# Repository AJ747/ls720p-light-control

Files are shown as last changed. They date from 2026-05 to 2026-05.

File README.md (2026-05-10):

# LS720P Light Control PCB
Controller for LS720P light using ATTINY5. Brightness is controlled using potentiometer. +5V input and switch for power on/off. Made in KiCad 10.

# Schematic

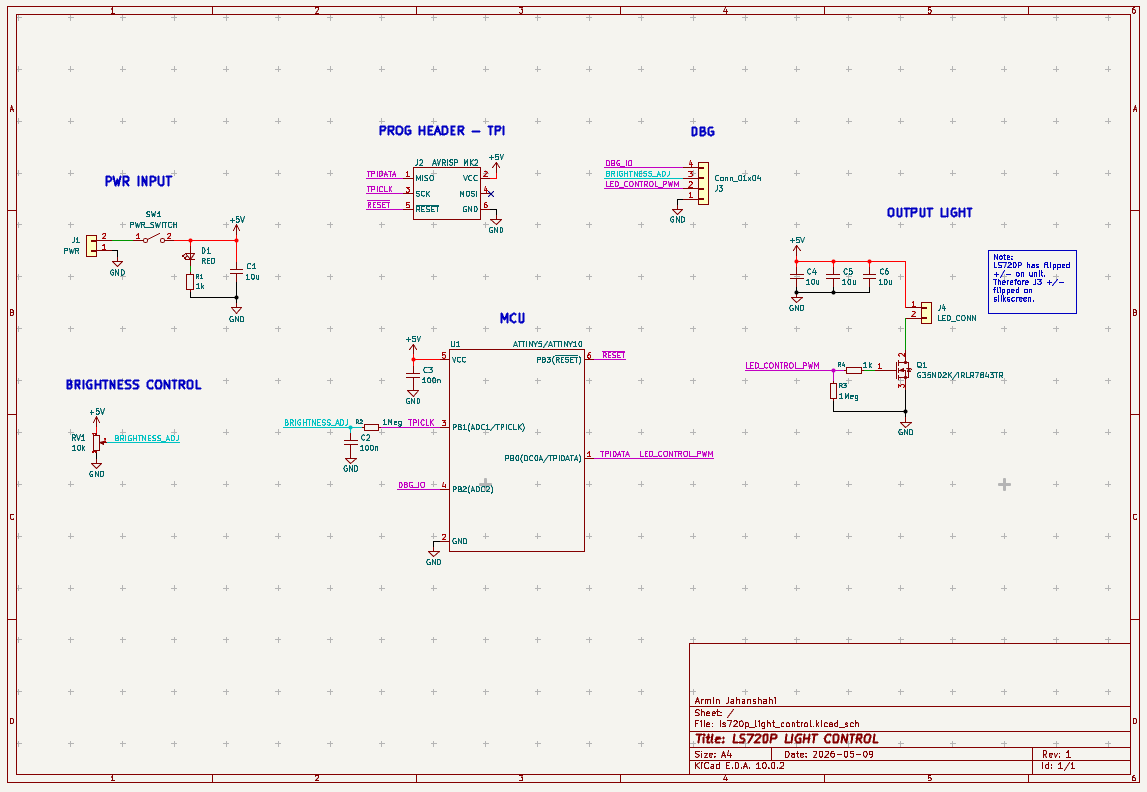
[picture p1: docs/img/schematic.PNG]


# Images of PCB

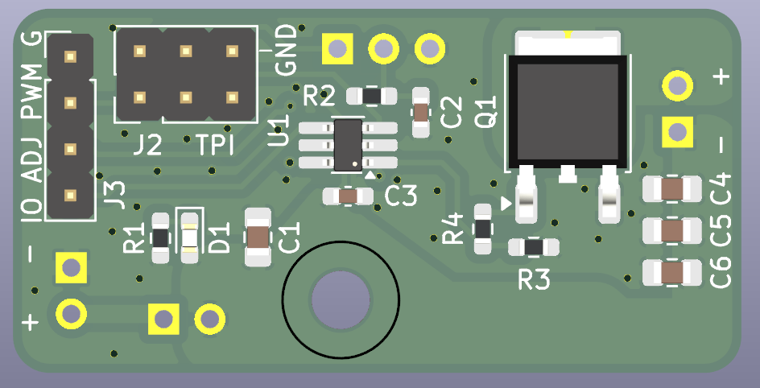
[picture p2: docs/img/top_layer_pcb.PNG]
Top layer


Top layer

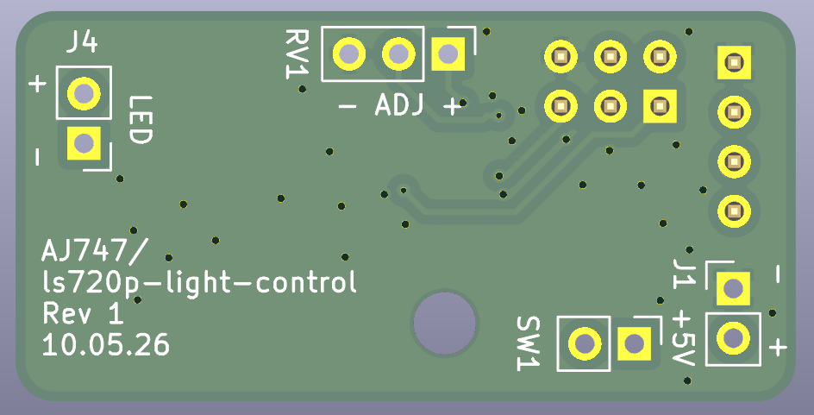
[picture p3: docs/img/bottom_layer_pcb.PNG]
Top layer


Bottom layer

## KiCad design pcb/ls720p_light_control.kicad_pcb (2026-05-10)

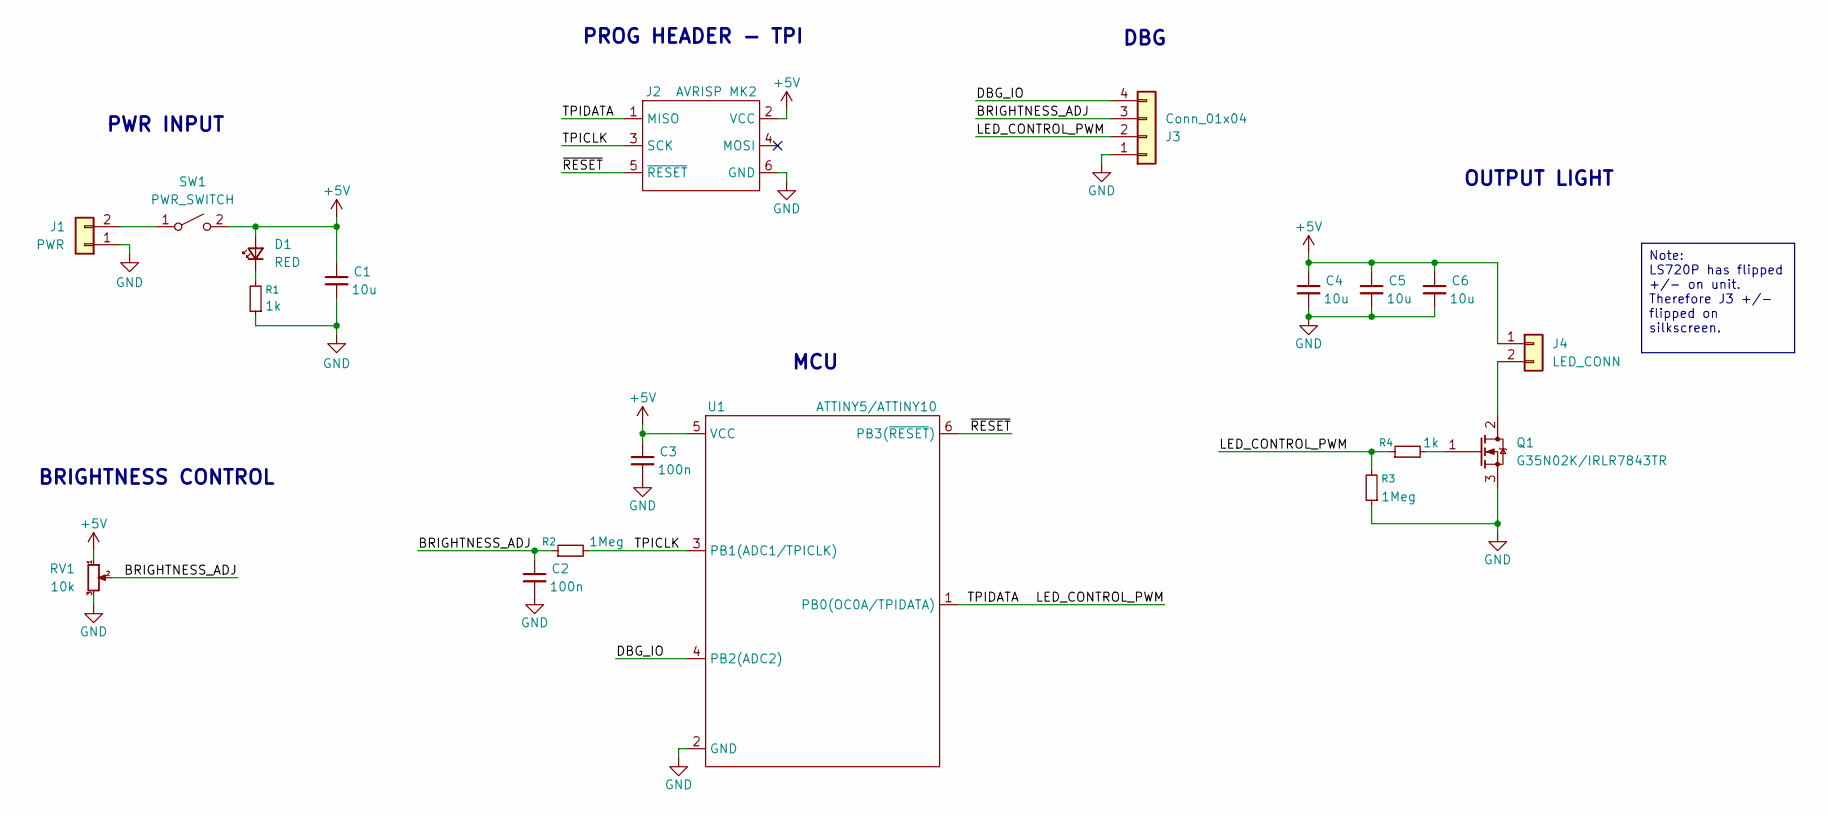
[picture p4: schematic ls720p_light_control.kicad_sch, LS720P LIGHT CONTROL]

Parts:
C1, C4, C5, C6: 10u; C_0805_2012Metric_Pad1.18x1.45mm_HandSolder
C2, C3: 100n; C_0603_1608Metric_Pad1.08x0.95mm_HandSolder
D1: RED; LED_0603_1608Metric_Pad1.05x0.95mm_HandSolder
J1: PWR; PinHeader_1x02_P2.54mm_Vertical
J2: AVRISP MK2; PinHeader_2x03_P2.54mm_Vertical
J3: Conn_01x04; PinHeader_1x04_P2.54mm_Vertical
J4: LED_CONN; PinHeader_1x02_P2.54mm_Vertical
Q1: G35N02K/IRLR7843TR; TO-252-2; Part G35N02K
R1, R4: 1k; R_0603_1608Metric_Pad0.98x0.95mm_HandSolder
R2, R3: 1Meg; R_0603_1608Metric_Pad0.98x0.95mm_HandSolder
RV1: 10k; PinHeader_1x03_P2.54mm_Vertical
SW1: PWR_SWITCH; PinHeader_1x02_P2.54mm_Vertical
U1: ATTINY5/ATTINY10; TSOT-23-6_HandSoldering; Part ATTINY5-TSHR

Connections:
+5V: C1.1, C3.1, C4.1, C5.1, C6.1, D1.2 (A), J2.2 (VCC), J4.1, RV1.1, SW1.2 (B), U1.5 (VCC)
/BRIGHTNESS_ADJ: C2.1, J3.3, R2.1, RV1.2
/DBG_IO: J3.4, U1.4 (PB2(ADC2))
/LED_CONTROL_PWM: J2.1 (MISO), J3.2, R3.2, R4.1, U1.1 (PB0(OC0A/TPIDATA))
/TPICLK: J2.3 (SCK), R2.2, U1.3 (PB1(ADC1/TPICLK))
/~RESET: J2.5 (~RESET), U1.6 (PB3(~RESET))
GND: C1.2, C2.2, C3.2, C4.2, C5.2, C6.2, J1.1, J2.6 (GND), J3.1, Q1.3 (S), R1.1, R3.1, RV1.3, U1.2 (GND)
unnamed: D1.1 (K), R1.2
unnamed: J1.2, SW1.1 (A)
unnamed: J4.2, Q1.2 (D)
unnamed: Q1.1 (G), R4.2

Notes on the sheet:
PROG HEADER - TPI
DBG
OUTPUT LIGHT
PWR INPUT
BRIGHTNESS CONTROL
MCU
Note: LS720P has flipped +/- on unit. Therefore J3 +/- flipped on silkscreen.

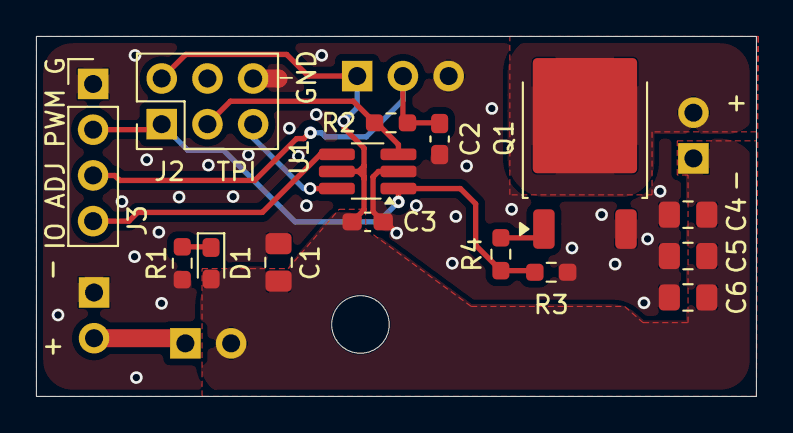
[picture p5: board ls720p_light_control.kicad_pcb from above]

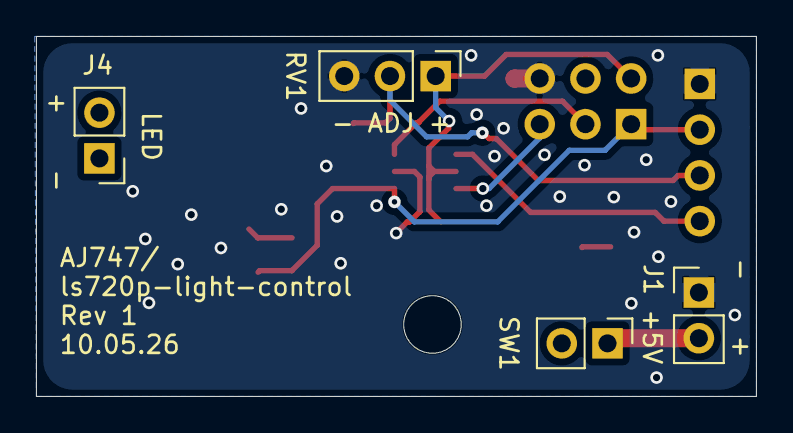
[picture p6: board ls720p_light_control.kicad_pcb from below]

Board: 2 copper layers, 40.0 x 20.0 mm, 19 parts (4 on the bottom side), 11 nets.

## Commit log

2026-05-09 Added schematic, pcb layout
    [ls720p_light_control.kicad_pcb, ls720p_light_control.kicad_sch]
2026-05-10 added ALT parts for LDO, MOSFET, MCU
    [ls720p_light_control.kicad_pcb, ls720p_light_control.kicad_sch]
2026-05-10 updated mcu info, specified package/part number
    [ls720p_light_control.kicad_sch]
2026-05-10 added notes to brightness max comp and output light section
    [ls720p_light_control.kicad_sch]
2026-05-10 done placing components
    [ls720p_light_control.kicad_pcb]
2026-05-10 pcb -> updated placing
    [ls720p_light_control.kicad_pcb]
2026-05-10 pcb -> finished layout, need to add stitching vias
    [ls720p_light_control.kicad_pcb, ls720p_light_control.kicad_sch]
2026-05-10 pcb -> layout completed
    [ls720p_light_control.kicad_pcb]
2026-05-10 generated gerber
2026-05-10 docs -> added pictures of pcb
2026-05-10 docs -> added schematic
2026-05-10 Update README with schematic and PCB images
    Added schematic and PCB images to README.
2026-05-10 removed +12v rail, everything is now +5v
    using +12v didn't acheive better brightness when using pwm, so keeping +5v
    [ls720p_light_control.kicad_pcb, ls720p_light_control.kicad_sch]
2026-05-10 updated pictures and pcb
    [ls720p_light_control.kicad_pcb]
